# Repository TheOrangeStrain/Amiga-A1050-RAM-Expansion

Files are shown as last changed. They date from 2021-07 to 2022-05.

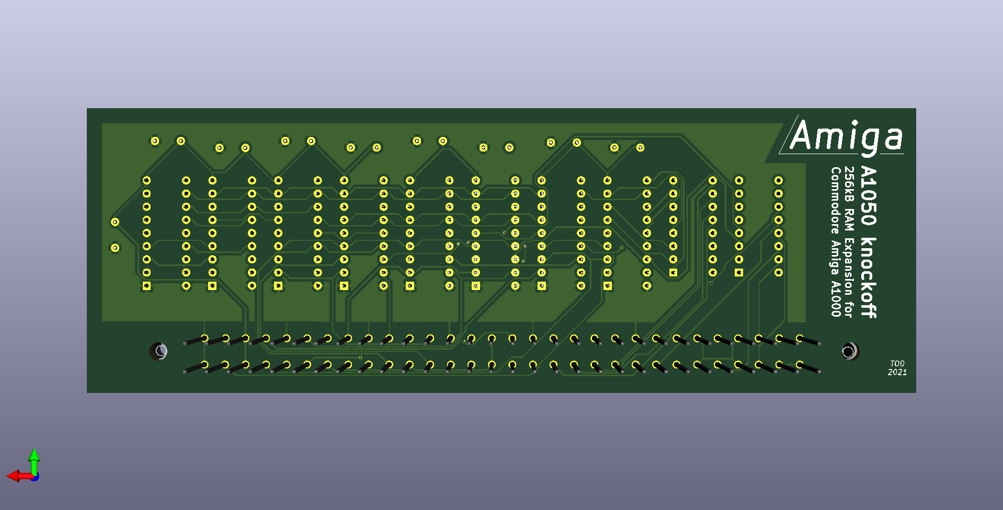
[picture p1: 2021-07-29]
pics/A1050_out.png

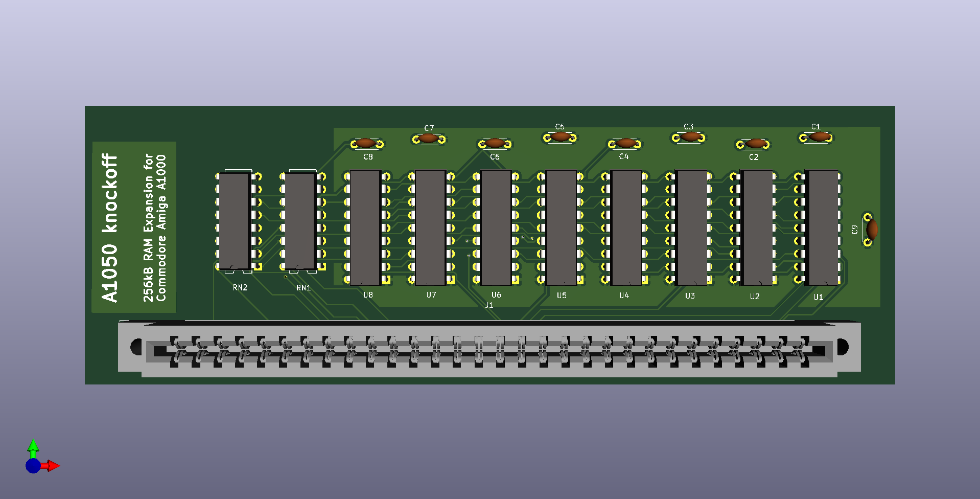
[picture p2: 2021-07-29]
pics/A1050_in.png

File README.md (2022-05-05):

# Amiga-A1050-RAM-Expansion
A knockoff of the A1050 front mounted RAM Expansion for the Amiga 1000

FYI: I noticed today (May 4, 2022) there is a seller on ebay [item desc: 256Kb RAM  AMIGA 1000 ( GREEN FULL SET )!!! . NEW IN STOCK] who has a number of fully assembled units for sale.  They are listed as shipping from Poland. Cost would be just over $31 USD, including shipping, to ship to the USA. 
This is NOT an endorsement of this seller.  Just passing on the information. --TOD

The problem:
I have a craiglist.com Amiga A1000 rescue. Many parts are missing. Basically I have the case, motherboard, daughterboard and power supply.  I was able to find key parts (Amiga 2000 keyboard, keyboard adapter for A1000, mouse and replacement Paula).  Howevery, the system only had 256k of RAM. This is not enough to do, well, just about anything.  Standalone RAM expansions like the A1050 are rare and often expensive if you are lucky enough to find one.  So I decided to design build my one A1050 knockoff.

Special thanks to Raffzahn on  retrocomputing.stackexchange.com. The information he supplied was critical.  Particularly since I didn't have an A1050 to probe – just online photo's and his explanation.  See this post for great info: 
https://retrocomputing.stackexchange.com/questions/5410/was-the-amiga-1000s-front-expansion-port-capable-of-anything-other-than-the-256

And the question I posted with responses from awesome and extremely helpful folks:
https://retrocomputing.stackexchange.com/questions/19893/amiga-a1050-schematic

The RAM chips are 64k x 4 bits.  Two chips are used to generate each byte.  There are low and high bytes to make up the 16 bit output.  Four pairs of chips means 64k x 4 = 256k bytes.

Drop in replacement chips (eg. From Texas Instruments) exist as well.  Other similar chips should work if the schematic is adjusted for different pinouts.  Be sure to check voltages and active levels (high / low) of course.

A fairly straight forward schematic, but I had never really thought much about RAM circuitry.  No doubt there are other ways to do this, but I wanted it to be quite similar to the original.  I used sockets for the ICs since these RAM chips have been around longer than the manufactures planned :)  Reliablity may be an issue so I wanted them to be easy to swap.  In fact, not surprisingly, 10 percent of the ones I purchased tested as bad.

There are PCB files for both unrouted and routed boards.  I find it easier to change the unrouted board then reroute nets.  I used freeRouting.jar to do the routing.

The BOM.ods file shows more detail on the parts I used.  My costs are listed and are from May and June of 2021 in U.S. Dollars.

No guarantees as I only have one A1000 to test with, but this seems to work on this system.  It would be good to hear experiences from anyone who builds one or has suggestions.

I am thinking of doing a version 2 that uses chips currently being manufactured.  If I get it working,
I will post that design and info as well.

Licencing:
CC0 1.0 Universal (CC0 1.0)
https://creativecommons.org/publicdomain/zero/1.0/

Feel free to use, modify or adapt for you own use, including commercial.

I hope this is useful for the Amiga community.
Enjoy and share.
TOD

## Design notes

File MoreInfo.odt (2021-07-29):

A knockoff of the A1050 RAM Expansion for the Amiga 1000

256KB of chip ram, front loaded, no configuration needed

The problem:

I had a craiglist.com Amiga A1000 rescue. Many parts are missing. Basically I had the case, motherboard, daughterboard and power supply. I was able to find key parts (Amiga 2000 keyboard, keyboard adapter for A1000 and replacement Paula) on ebay. Howevery, the system only had 256k of RAM. This is not enough to do, well, just about anything. Standalone RAM expansions like the A1050 are rare and often expensive if you are lucky enough to find one. So I decided to design build my one A1050 knockoff.

Special thanks to Raffzahn on retrocomputing.stackexchange.com. The information he supplied was critical. Particularly since I didn't have an A1050 to probe – just online photo's and his explanation. See this post for great info:

https://retrocomputing.stackexchange.com/questions/5410/was-the-amiga-1000s-front-expansion-port-capable-of-anything-other-than-the-256

And the question I posted with responses from awesome and extremely helpful folks:

https://retrocomputing.stackexchange.com/questions/19893/amiga-a1050-schematic

The RAM chips are 64k x 4 bits. Two chips are used to generate each byte. There are low and high bytes to make up the 16 bit output.

Drop in replacement chips (eg. From Texas Instruments) exist as well. Other similar chips should work if the schematic is adjusted for different pinouts. Be sure to check voltages and active levels (high / low) of course.

A fairly straight forward schematic, but I had never really thought much about RAM circuitry. No doubt there are other ways to do this, but I wanted it to be quite similar to the original. I used sockets for the ICs since these RAM chips have been around longer than the manufactures planned : ) Reliablity may be an issue so I wanted them to be easy to swap. In fact, not surprisingly, 10 percent of the ones I purchased tested as bad.

There are PCB files for both unrouted and routed boards. I find it easier to change the unrouted board then reroute nets. I used freeRouting.jar to do the routing.

The BOM.ods file shows more detail on the parts I used. My costs are listed and are from May and June of 2021 in U.S. Dollars.

No guarantees as I only have one A1000 to test with, but this seems to work on this system. It would be good to hear experiences from anyone who builds one or has suggestions.

I am thinking of doing a version 2 that uses chips currently being manufactured. If I get it working,

I will post that design and info as well.

Licencing:

CC0 1.0 Universal (CC0 1.0)

https://creativecommons.org/publicdomain/zero/1.0/

Feel free to use, modify or adapt for you own use, including commercial.

I hope this is useful for the Amiga community.

Enjoy and share.

TOD

BOM

RAM, HM50464P-15 (64k x 4) or equivalent | 8 | https://www.questcomp.com/part/4/HM50464P-15/216503153
DIP-16 socket | 2 | https://www.mouser.com/ProductDetail/571-1-2199298-4
DIP-18 socket | 8 | https://www.mouser.com/ProductDetail/649-DILB18P223TLF
Card edge connector, 60 position | 1 | https://www.mouser.com/ProductDetail/587-337-060-540-202
Resistor array 22 ohm | 1 | https://www.mouser.com/ProductDetail/652-4116R-1LF-22
Resistor array 39 ohm | 1 | https://www.mouser.com/ProductDetail/652-4116R-1LF-39
Capacitor, 0.22uf | 8 | Https://www.mouser.com/ProductDetail/581-SR215C224KARTR2
Capacitor, 10uf | 1 | https://www.mouser.com/ProductDetail/81-RDEC71H106K3K1H3B
PCB | 1 | Anywhere. I used https://www.nextpcb.com/
Solder, flux, tools

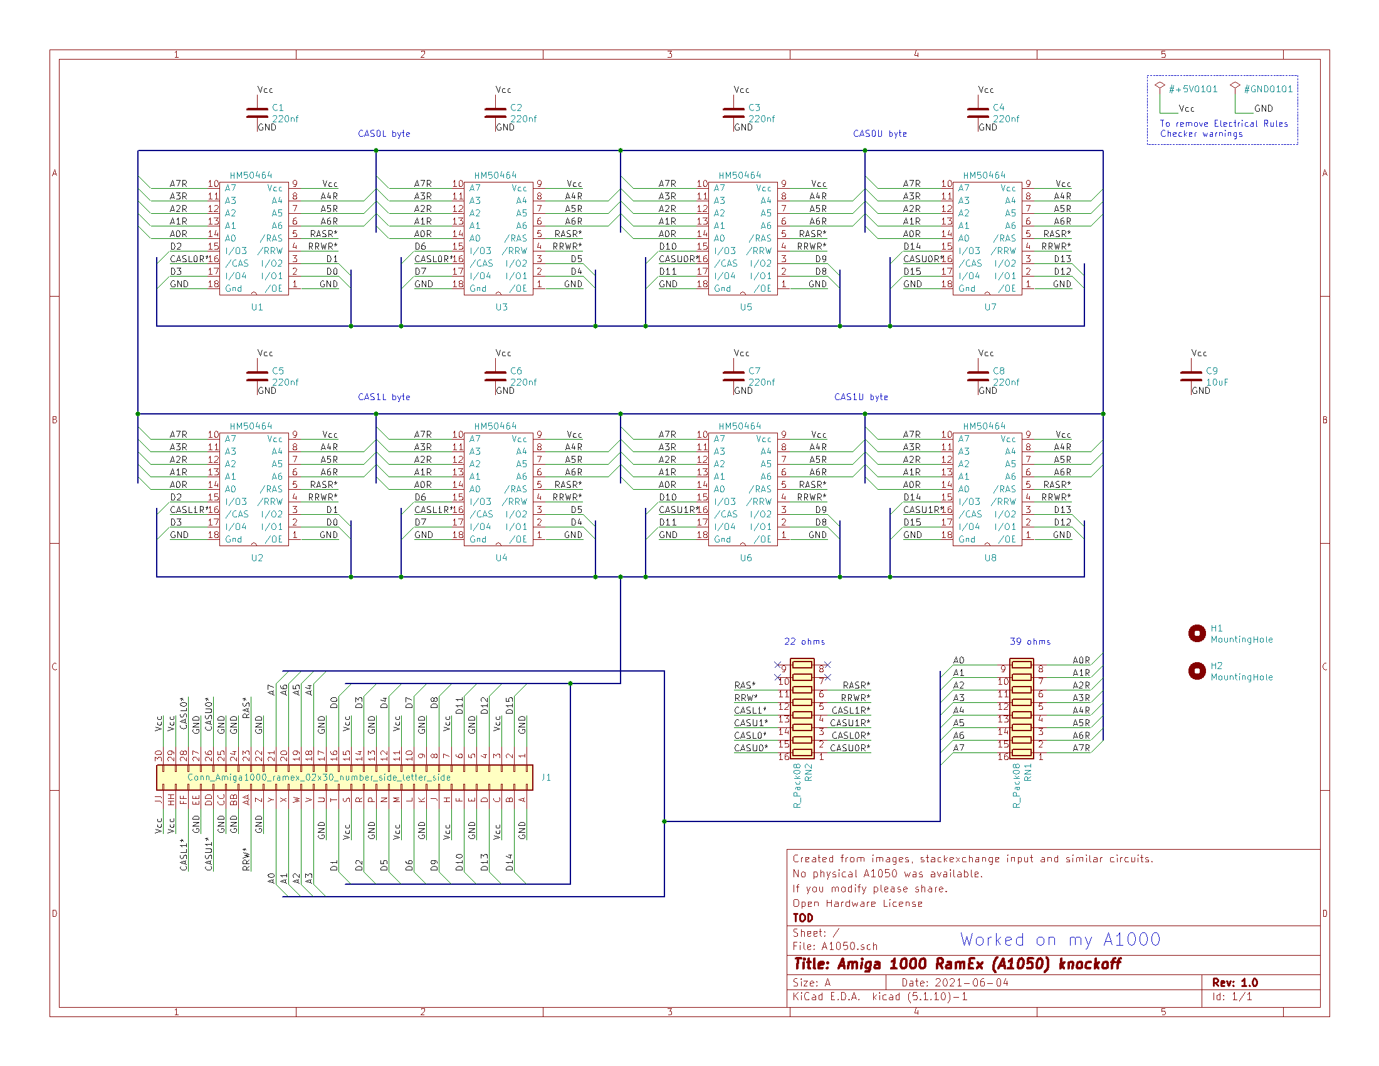
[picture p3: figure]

Illustration 1: Schematic in Kicad

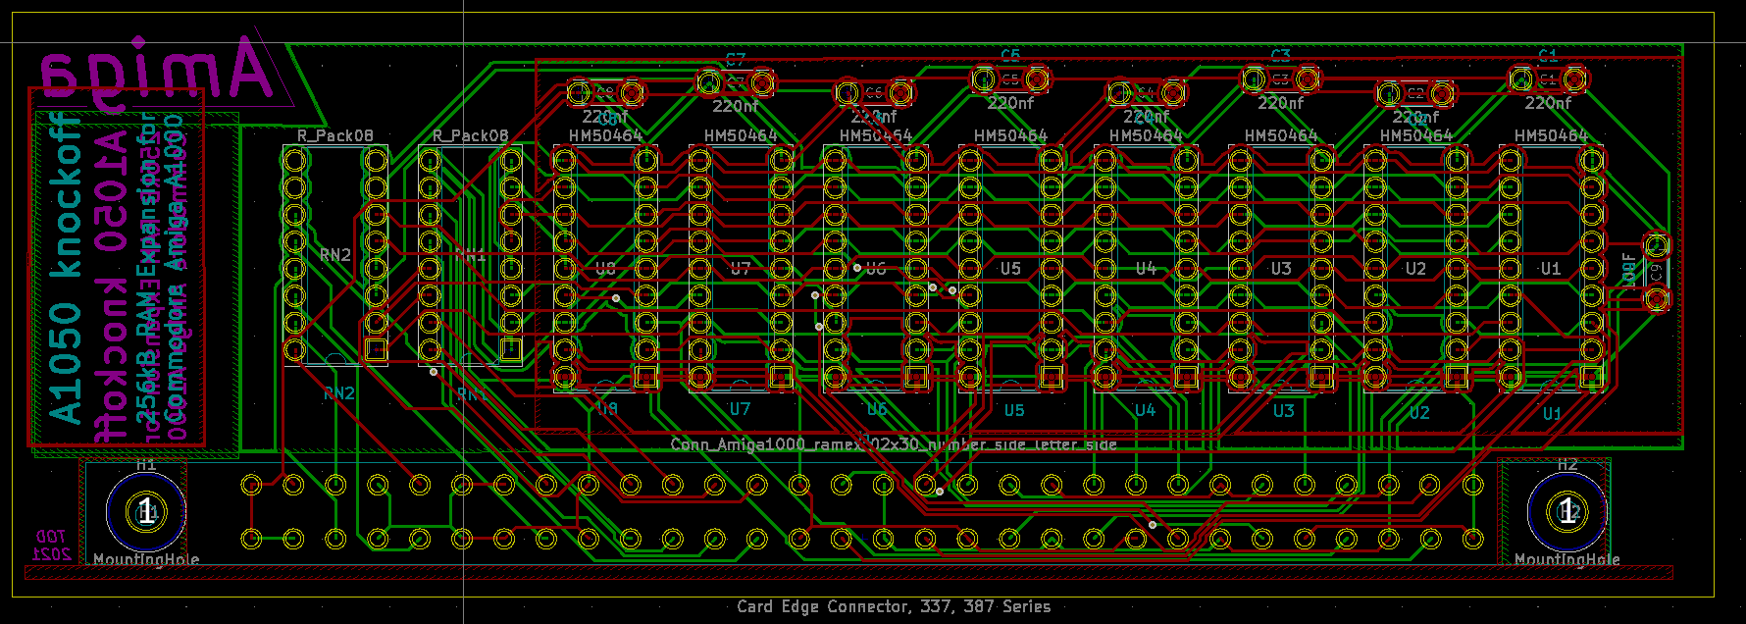
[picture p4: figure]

Illustration 2: PCB in Kicad after freeRouting

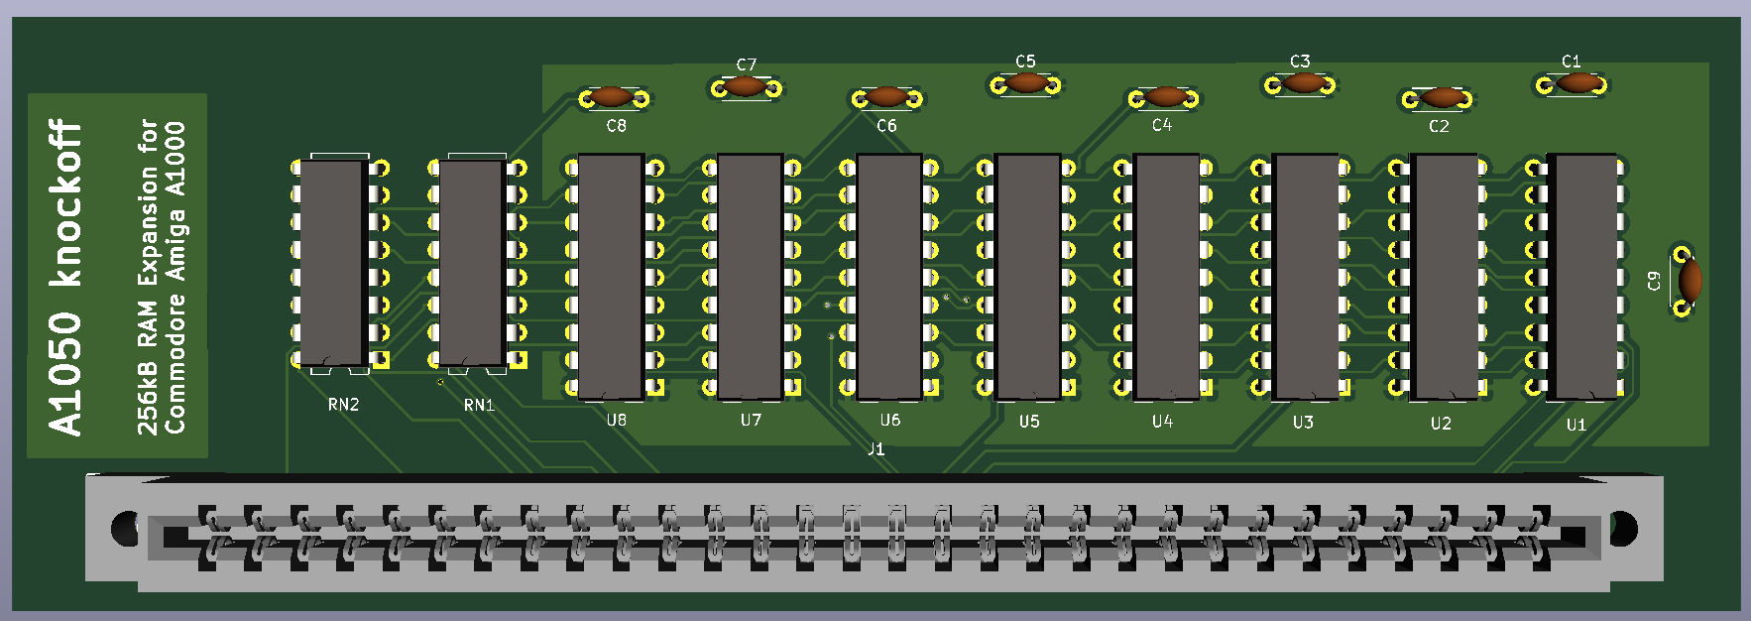
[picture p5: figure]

Illustration 3: Kicad rendered image

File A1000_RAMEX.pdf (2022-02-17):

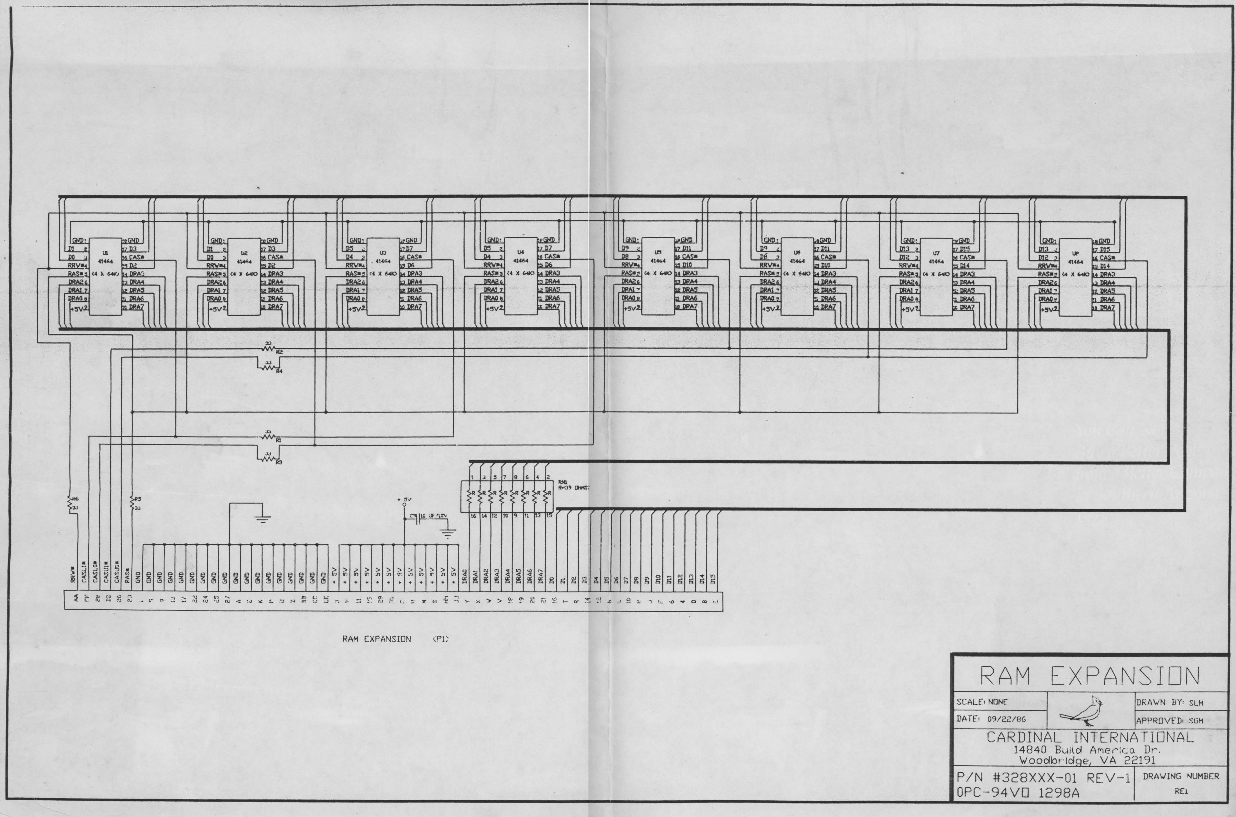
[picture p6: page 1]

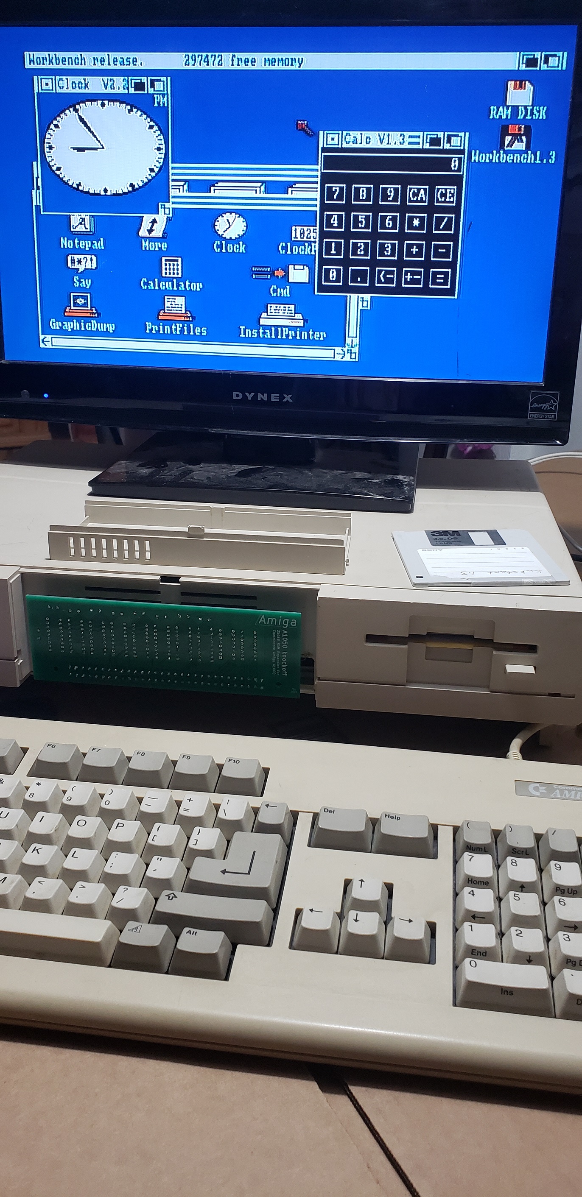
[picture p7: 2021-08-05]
pics/yesA1050.jpg

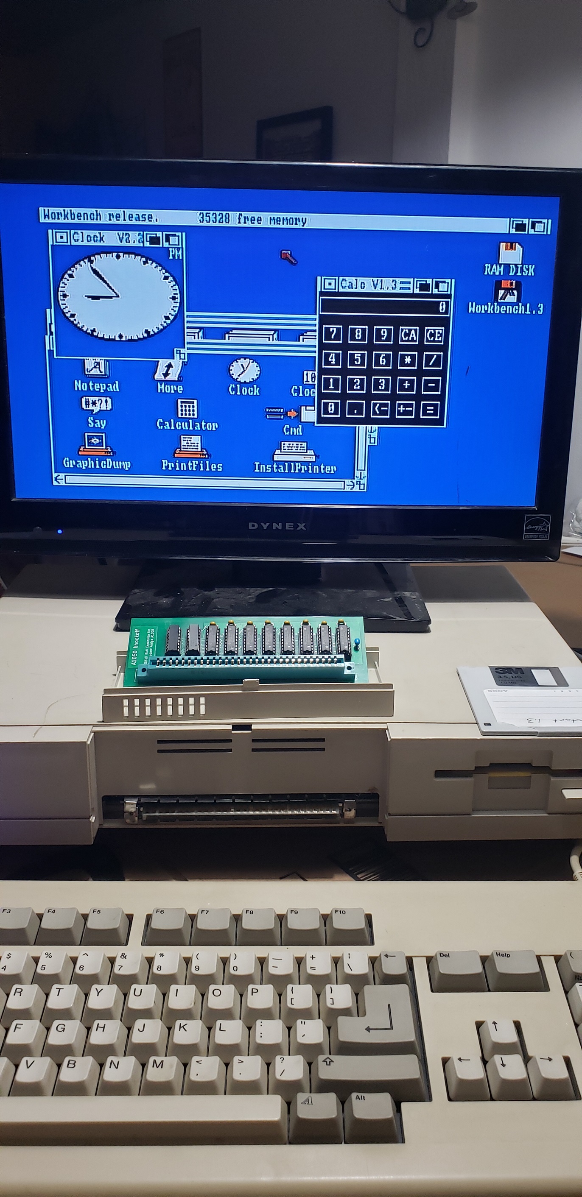
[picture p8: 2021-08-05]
pics/noA1050.jpg

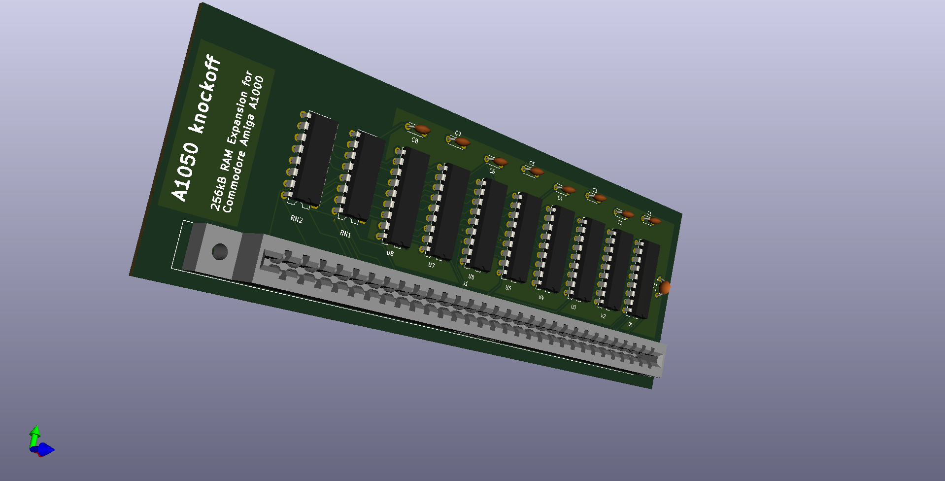
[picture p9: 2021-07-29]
pics/A1050_angled.png

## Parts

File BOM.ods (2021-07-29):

 |  |  | for reference only. 1H2021 costs in USD$
Item # | Description | Number | Unit cost | Cost | Ship | Total | Link | datasheet
1 | RAM, HM50464P-15 (64k x 4) or equivalent | 8 | 1.88 | 15 | 11 | 26 | https://www.questcomp.com/part/4/HM50464P-15/216503153 | https://rocelec.widen.net/view/pdf/i3gbnikep9/TXIIS146290-1.pdf?t.download=true&u=5oefqw
2 | DIP-16 socket | 2 | 0.26 | 0.52 | 7.99 | 8.51 | https://www.mouser.com/ProductDetail/571-1-2199298-4 | https://www.mouser.com/datasheet/2/418/7/ENG_CD_2199298_A_baseFilename-2029528.pdf
3 | DIP-18 socket | 8 | 0.29 | 2.3 |  | 2.3 | https://www.mouser.com/ProductDetail/649-DILB18P223TLF | https://www.mouser.com/datasheet/2/18/10052485-1361079.pdf
4 | Card edge connector, 60 position | 1 | 14.44 | 14.44 |  | 14.44 | https://www.mouser.com/ProductDetail/587-337-060-540-202 | https://www.mouser.com/datasheet/2/123/3/337_060_540_202___EDAC_Card_Edge_Connector-2227262.pdf
5 | Resistor array 22 ohm | 1 | 1.43 | 1.43 |  | 1.43 | https://www.mouser.com/ProductDetail/652-4116R-1LF-22 | https://www.mouser.com/datasheet/2/54/4100R-776985.pdf
6 | resistor array 39 ohm | 1 | 1.4 | 1.4 |  | 1.4 | https://www.mouser.com/ProductDetail/652-4116R-1LF-22 | https://www.mouser.com/datasheet/2/54/4100R-776985.pdf
7 | Capacitor, 0.22uf | 8 | 0.26 | 2.08 |  | 2.08 | https://www.mouser.com/ProductDetail/581-SR215C224KARTR2 | https://www.mouser.com/datasheet/2/40/SR_Series-1016911.pdf
8 | Capacitor, 10uf | 1 | 1.32 | 1.32 |  | 1.32 | https://www.mouser.com/ProductDetail/81-RDEC71H106K3K1H3B | https://www.mouser.com/datasheet/2/281/RDE_X7R_X7S_25V_100V_E-1671041.pdf
9 | Circuit card | 1 | 3.39 | 3.39 | 16.52 | 19.91 | https://www.nextpcb.com/ | Note you may need to purchase additional PCBs
 |  |  |  |  | Total | $77.39

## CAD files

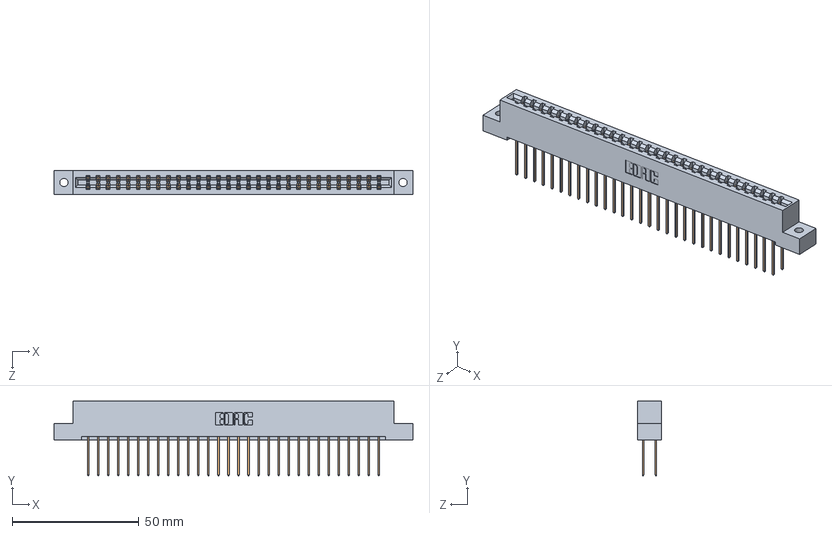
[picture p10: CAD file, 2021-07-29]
Kicad_files/337-060-540-202 - EDAC Card Edge Connector.STEP
141.9 x 29.5 x 9.40 mm
337 Part_Flush Mounting Lugs - 0.128 Dia

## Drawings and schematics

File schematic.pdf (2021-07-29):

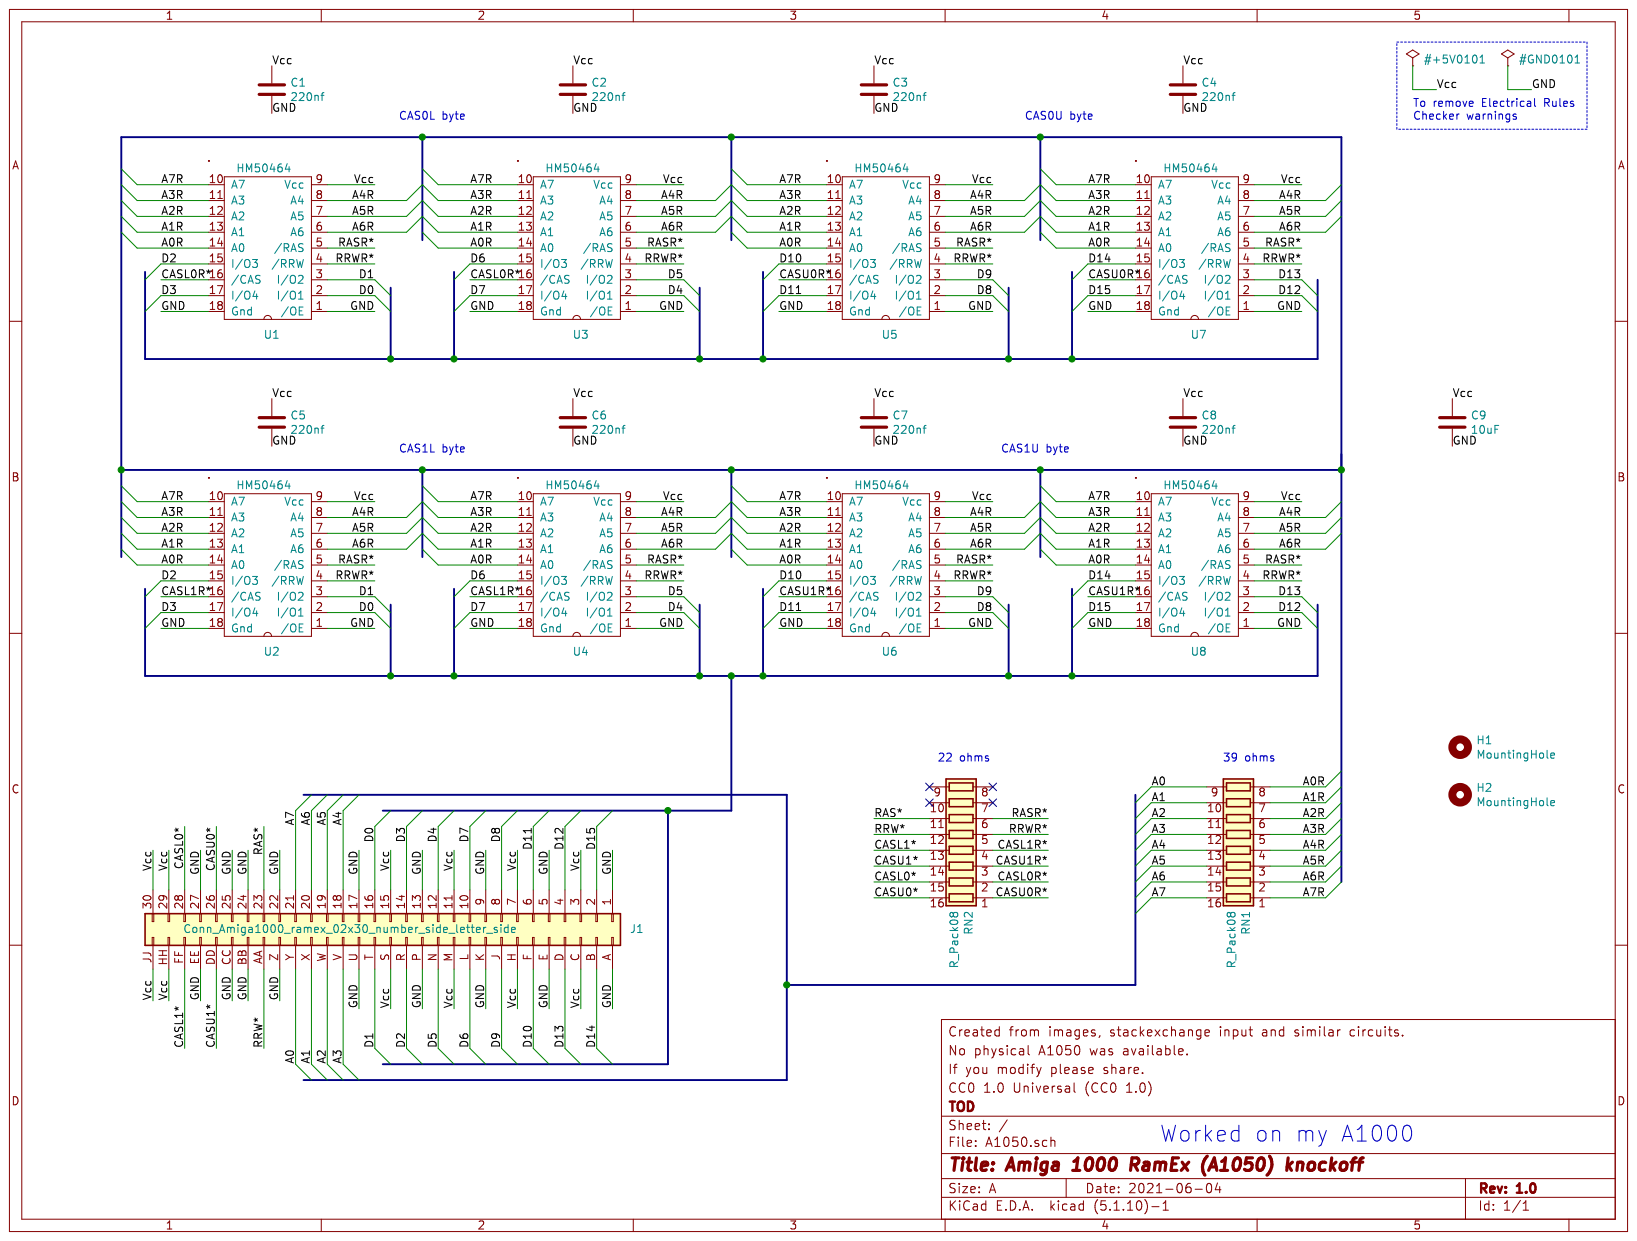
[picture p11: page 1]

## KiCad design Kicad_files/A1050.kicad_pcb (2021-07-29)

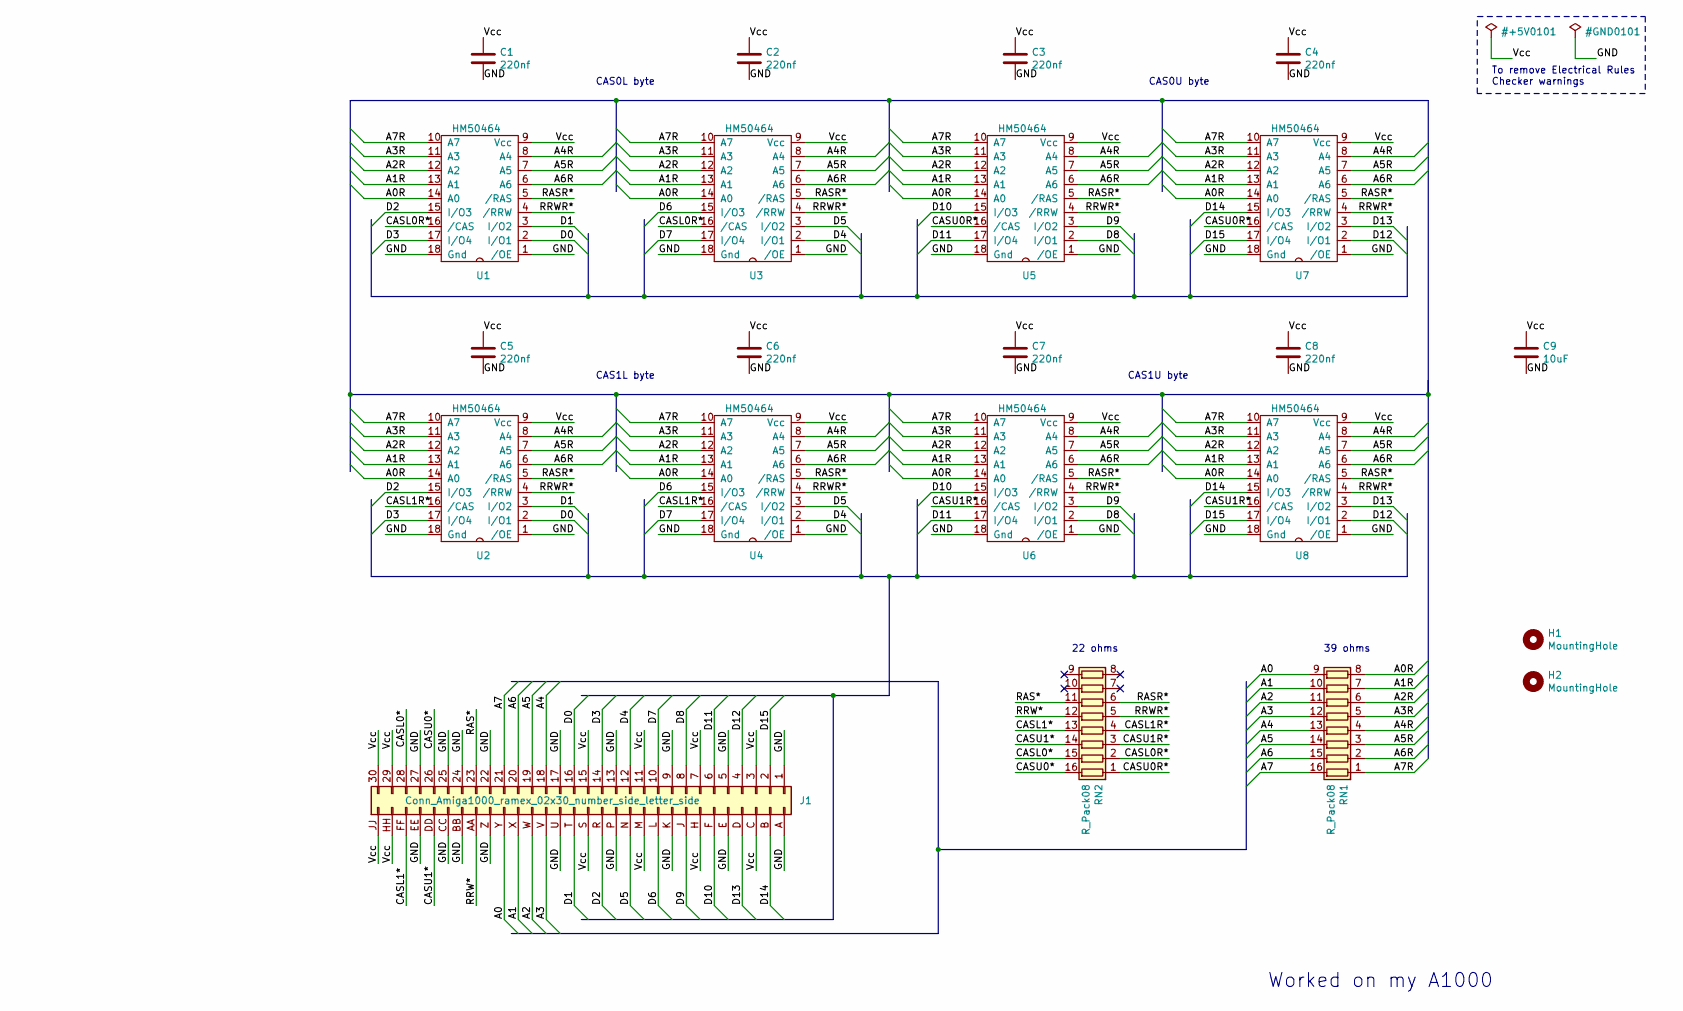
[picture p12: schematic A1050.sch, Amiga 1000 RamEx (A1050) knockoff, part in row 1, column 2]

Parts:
C1, C2, C3, C4, C6, C7, C8: 220nf; C_Disc_D4.3mm_W1.9mm_P5.00mm
C5: 220nf; C_Disc_D4.3mm_W1.9mm_P5.00mm; Manu Part SR215C224KARTR2
C9: 10uF; C_Disc_D4.3mm_W1.9mm_P5.00mm
H1, H2: MountingHole; MountingHole_3.5mm
J1: Conn_Amiga1000_ramex_02x30_number_side_letter_side; Connector_horizontal_amiga1.04_GREEN
RN1, RN2: R_Pack08; DIP-16_W7.62mm
U1, U2, U3, U4, U5, U6, U7, U8: HM50464; DIP-18_W7.62mm

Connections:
/A0: J1.Y, RN1.9 (R8.2)
/A0R: RN1.8 (R8.1), U1.14 (A0), U2.14 (A0), U3.14 (A0), U4.14 (A0), U5.14 (A0), U6.14 (A0), U7.14 (A0), U8.14 (A0)
/A1: J1.X, RN1.10 (R7.2)
/A1R: RN1.7 (R7.1), U1.13 (A1), U2.13 (A1), U3.13 (A1), U4.13 (A1), U5.13 (A1), U6.13 (A1), U7.13 (A1), U8.13 (A1)
/A2: J1.W, RN1.11 (R6.2)
/A2R: RN1.6 (R6.1), U1.12 (A2), U2.12 (A2), U3.12 (A2), U4.12 (A2), U5.12 (A2), U6.12 (A2), U7.12 (A2), U8.12 (A2)
/A3: J1.V, RN1.12 (R5.2)
/A3R: RN1.5 (R5.1), U1.11 (A3), U2.11 (A3), U3.11 (A3), U4.11 (A3), U5.11 (A3), U6.11 (A3), U7.11 (A3), U8.11 (A3)
/A4: J1.18, RN1.13 (R4.2)
/A4R: RN1.4 (R4.1), U1.8 (A4), U2.8 (A4), U3.8 (A4), U4.8 (A4), U5.8 (A4), U6.8 (A4), U7.8 (A4), U8.8 (A4)
/A5: J1.19, RN1.14 (R3.2)
/A5R: RN1.3 (R3.1), U1.7 (A5), U2.7 (A5), U3.7 (A5), U4.7 (A5), U5.7 (A5), U6.7 (A5), U7.7 (A5), U8.7 (A5)
/A6: J1.20, RN1.15 (R2.2)
/A6R: RN1.2 (R2.1), U1.6 (A6), U2.6 (A6), U3.6 (A6), U4.6 (A6), U5.6 (A6), U6.6 (A6), U7.6 (A6), U8.6 (A6)
/A7: J1.21, RN1.16 (R1.2)
/A7R: RN1.1 (R1.1), U1.10 (A7), U2.10 (A7), U3.10 (A7), U4.10 (A7), U5.10 (A7), U6.10 (A7), U7.10 (A7), U8.10 (A7)
/CASL0*: J1.28, RN2.15 (R2.2)
/CASL0R*: RN2.2 (R2.1), U1.16 (/CAS), U3.16 (/CAS)
/CASL1*: J1.FF, RN2.13 (R4.2)
/CASL1R*: RN2.4 (R4.1), U2.16 (/CAS), U4.16 (/CAS)
/CASU0*: J1.26, RN2.16 (R1.2)
/CASU0R*: RN2.1 (R1.1), U5.16 (/CAS), U7.16 (/CAS)
/CASU1*: J1.DD, RN2.14 (R3.2)
/CASU1R*: RN2.3 (R3.1), U6.16 (/CAS), U8.16 (/CAS)
/D0: J1.16, U1.2 (I/O1), U2.2 (I/O1)
/D1: J1.T, U1.3 (I/O2), U2.3 (I/O2)
/D2: J1.R, U1.15 (I/O3), U2.15 (I/O3)
/D3: J1.14, U1.17 (I/O4), U2.17 (I/O4)
/D4: J1.12, U3.2 (I/O1), U4.2 (I/O1)
/D5: J1.N, U3.3 (I/O2), U4.3 (I/O2)
/D6: J1.L, U3.15 (I/O3), U4.15 (I/O3)
/D7: J1.10, U3.17 (I/O4), U4.17 (I/O4)
/D8: J1.8, U5.2 (I/O1), U6.2 (I/O1)
/D9: J1.J, U5.3 (I/O2), U6.3 (I/O2)
/D10: J1.F, U5.15 (I/O3), U6.15 (I/O3)
/D11: J1.6, U5.17 (I/O4), U6.17 (I/O4)
/D12: J1.4, U7.2 (I/O1), U8.2 (I/O1)
/D13: J1.D, U7.3 (I/O2), U8.3 (I/O2)
/D14: J1.B, U7.15 (I/O3), U8.15 (I/O3)
/D15: J1.2, U7.17 (I/O4), U8.17 (I/O4)
/RAS*: J1.23, RN2.11 (R6.2)
/RASR*: RN2.6 (R6.1), U1.5 (/RAS), U2.5 (/RAS), U3.5 (/RAS), U4.5 (/RAS), U5.5 (/RAS), U6.5 (/RAS), U7.5 (/RAS), U8.5 (/RAS)
/RRW*: J1.AA, RN2.12 (R5.2)
/RRWR*: RN2.5 (R5.1), U1.4 (/RRW), U2.4 (/RRW), U3.4 (/RRW), U4.4 (/RRW), U5.4 (/RRW), U6.4 (/RRW), U7.4 (/RRW), U8.4 (/RRW)

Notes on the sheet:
CAS0L byte
Worked on my A1000
CAS1L byte
CAS0U byte
CAS1U byte
39 ohms
22 ohms
To remove Electrical Rules Checker warnings

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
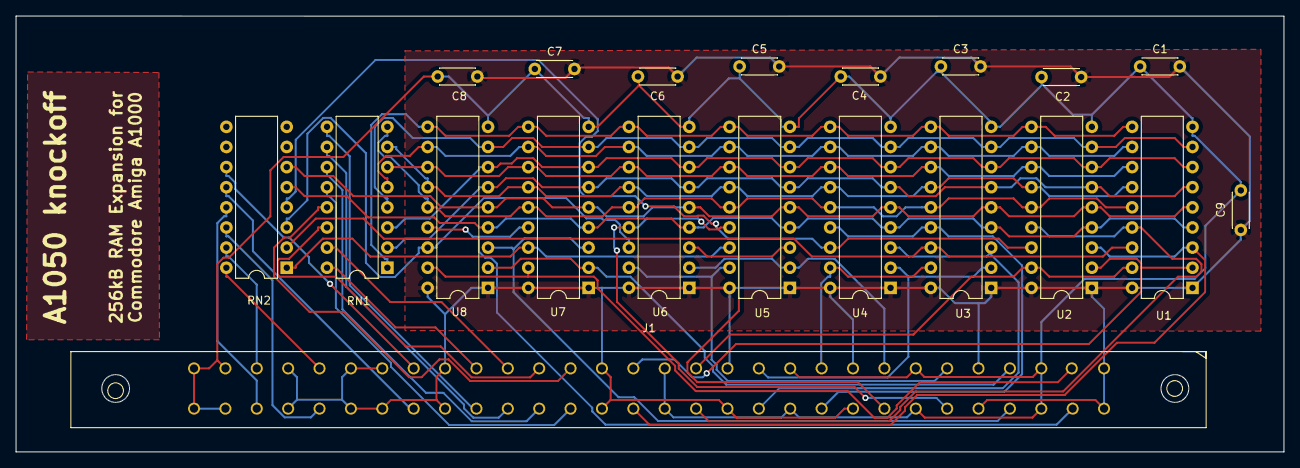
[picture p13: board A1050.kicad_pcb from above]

Board: 2 copper layers, 160.0 x 55.0 mm, 22 parts (0 on the bottom side), 46 nets.

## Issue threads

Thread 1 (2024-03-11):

One Resistor Array in the BOM has the wrong Mouser link.

denis2342, 2024-03-11:
One Resistor Array in the BOM has the wrong Mouser link.

TheOrangeStrain, 2024-03-12:
Corrected. Thanks for letting me know.

Closed 2024-03-12.

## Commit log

2021-07-29 Add files via upload
    Initial upload
    [337-060-540-202 - EDAC Card Edge Connector.STEP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]
2022-02-17 Original RAMEX schematic
    I recently acquired a handful of Amiga 1000 schematics. Included was one for the RAM Expansion. It is now here for your reference.
    Enjoy,
    TheOrangeDude
2022-05-05 Update README.md
    Info on some assembled units listed on ebay.
